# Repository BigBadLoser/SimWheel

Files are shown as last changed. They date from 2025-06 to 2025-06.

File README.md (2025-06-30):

# SimWheel

Source files for my Ferrari SF90 F1 wheel. Uses a PGA2350 as the main processor, 
also uses an Adafruit USB hub of some sort, allows one cable for output even with the VoCore usb screen installed :)

###TODO:
- Fix HAT switch wiring.
- Move upper led_din to a GPIO pin that supports PIO (oops)
- add connectors for the rear 2 push buttons that i forgot

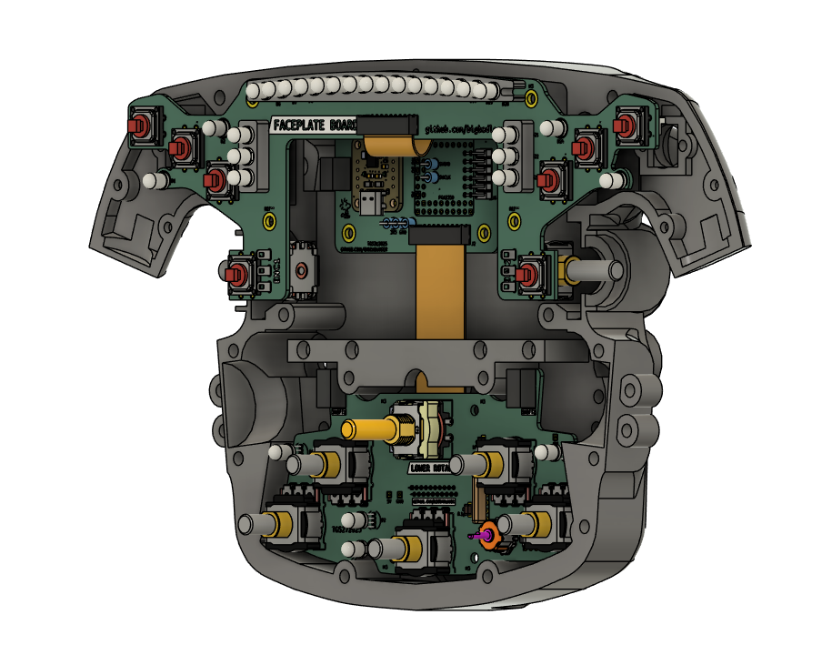
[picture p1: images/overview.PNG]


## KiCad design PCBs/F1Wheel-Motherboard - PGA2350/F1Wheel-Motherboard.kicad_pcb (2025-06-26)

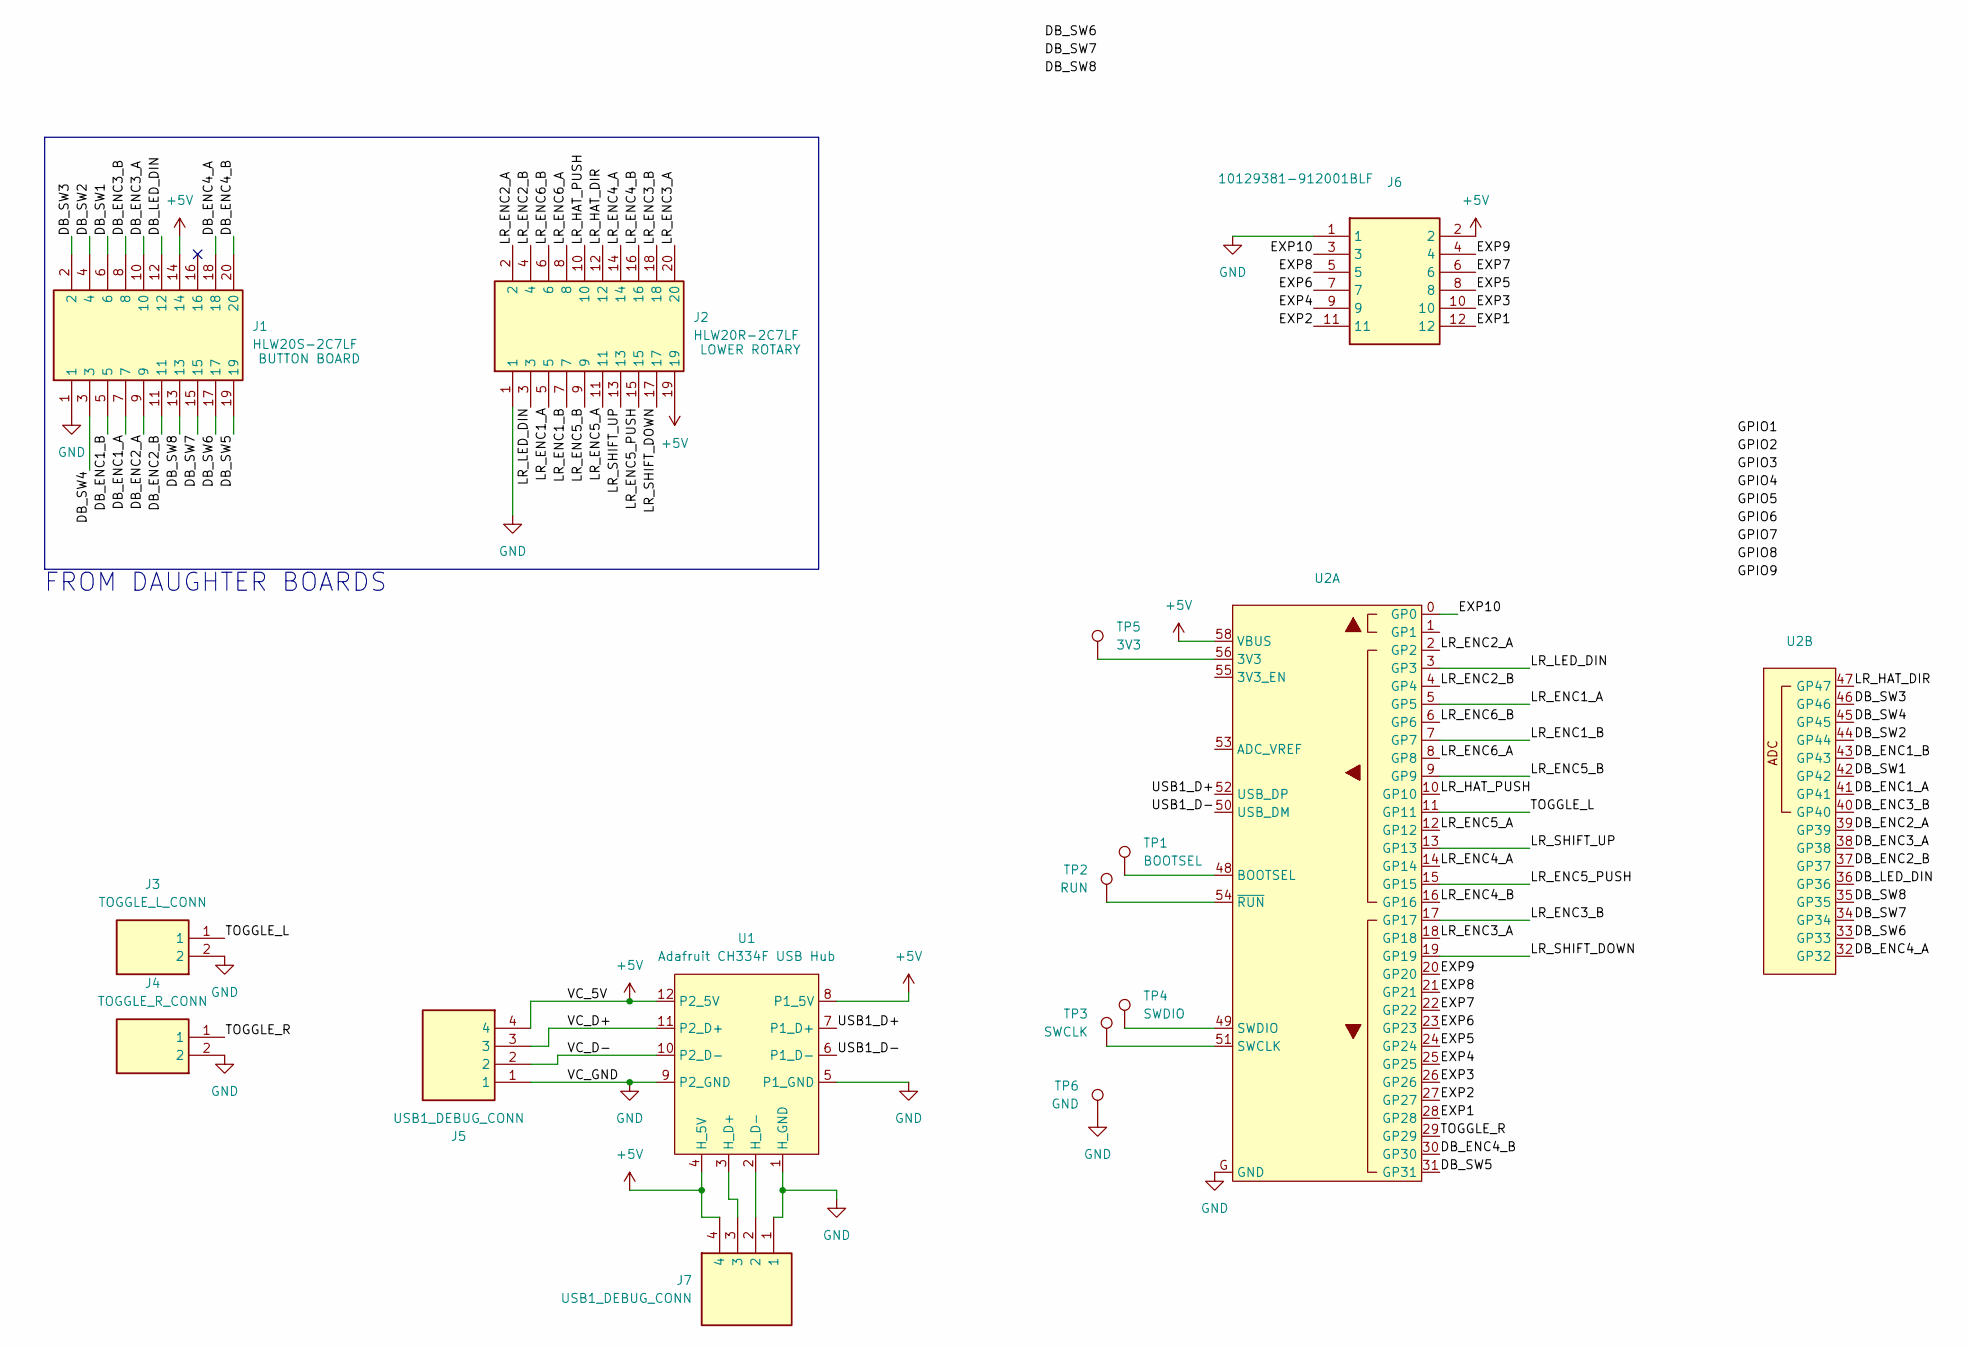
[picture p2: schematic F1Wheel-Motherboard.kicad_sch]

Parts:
J1: HLW20S-2C7LF; AMPHENOL_HLW20S2C7LF; Mouser Part Number 649-HLW16R-2C7LF
J2: HLW20R-2C7LF; AMPHENOL_HLW20R-2C7LF; Mouser Part Number 649-HLW16R-2C7LF
J3: TOGGLE_L_CONN; B02BPASKLFSN; Mouser Part Number 306-B02BPASKLFSN
J4: TOGGLE_R_CONN; B02BPASKLFSN; Mouser Part Number 306-B02BPASKLFSN
J5, J7: USB1_DEBUG_CONN; B04BPASKLFSN; Mouser Part Number 306-B04BPASKLFSN
J6: 10129381-912001BLF; HDRV12W67P254_2X6_1524X483X858P; Manufacturer_Part_Number 10129381-912001BLF
TP1: BOOTSEL; TestPoint_Keystone_5005-5009_Compact
TP2: RUN; TestPoint_Keystone_5005-5009_Compact
TP3: SWCLK; TestPoint_Keystone_5005-5009_Compact
TP4: SWDIO; TestPoint_Keystone_5005-5009_Compact
TP5: 3V3; TestPoint_Keystone_5005-5009_Compact
TP6: GND; TestPoint_Keystone_5005-5009_Compact
U1: Adafruit CH334F USB Hub; Adafruit_CH334F_2Port
U2: PGA2350_ALT

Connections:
+5V: J1.14, J2.19, J5.4, J6.2, J7.4, U1.4 (H_5V), U1.8 (P1_5V), U1.12 (P2_5V), U2.58 (VBUS)
/DB_ENC1_A: J1.7, U2.41 (GP41)
/DB_ENC1_B: J1.5, U2.43 (GP43)
/DB_ENC2_A: J1.9, U2.39 (GP39)
/DB_ENC2_B: J1.11, U2.37 (GP37)
/DB_ENC3_A: J1.10, U2.38 (GP38)
/DB_ENC3_B: J1.8, U2.40 (GP40)
/DB_ENC4_A: J1.18, U2.32 (GP32)
/DB_ENC4_B: J1.20, U2.30 (GP30)
/DB_LED_DIN: J1.12, U2.36 (GP36)
/DB_SW1: J1.6, U2.42 (GP42)
/DB_SW2: J1.4, U2.44 (GP44)
/DB_SW3: J1.2, U2.46 (GP46)
/DB_SW4: J1.3, U2.45 (GP45)
/DB_SW5: J1.19, U2.31 (GP31)
/DB_SW6: J1.17, U2.33 (GP33)
/DB_SW7: J1.15, U2.34 (GP34)
/DB_SW8: J1.13, U2.35 (GP35)
/EXP1: J6.12, U2.28 (GP28)
/EXP2: J6.11, U2.27 (GP27)
/EXP3: J6.10, U2.26 (GP26)
/EXP4: J6.9, U2.25 (GP25)
/EXP5: J6.8, U2.24 (GP24)
/EXP6: J6.7, U2.23 (GP23)
/EXP7: J6.6, U2.22 (GP22)
/EXP8: J6.5, U2.21 (GP21)
/EXP9: J6.4, U2.20 (GP20)
/EXP10: J6.3, U2.0 (GP0)
/LR_ENC1_A: J2.5, U2.5 (GP5)
/LR_ENC1_B: J2.7, U2.7 (GP7)
/LR_ENC2_A: J2.2, U2.2 (GP2)
/LR_ENC2_B: J2.4, U2.4 (GP4)
/LR_ENC3_A: J2.20, U2.18 (GP18)
/LR_ENC3_B: J2.18, U2.17 (GP17)
/LR_ENC4_A: J2.14, U2.14 (GP14)
/LR_ENC4_B: J2.16, U2.16 (GP16)
/LR_ENC5_A: J2.11, U2.12 (GP12)
/LR_ENC5_B: J2.9, U2.9 (GP9)
/LR_ENC5_PUSH: J2.15, U2.15 (GP15)
/LR_ENC6_A: J2.8, U2.8 (GP8)
/LR_ENC6_B: J2.6, U2.6 (GP6)
/LR_HAT_DIR: J2.12, U2.47 (GP47)
/LR_HAT_PUSH: J2.10, U2.10 (GP10)
/LR_LED_DIN: J2.3, U2.3 (GP3)
/LR_SHIFT_DOWN: J2.17, U2.19 (GP19)
/LR_SHIFT_UP: J2.13, U2.13 (GP13)
/TOGGLE_L: J3.1, U2.11 (GP11)
/TOGGLE_R: J4.1, U2.29 (GP29)
/USB1_D+: U1.7 (P1_D+), U2.52 (USB_DP)
/USB1_D-: U1.6 (P1_D-), U2.50 (USB_DM)
/VC_D+: J5.3, U1.11 (P2_D+)
/VC_D-: J5.2, U1.10 (P2_D-)
GND: J1.1, J2.1, J3.2, J4.2, J5.1, J6.1, J7.1, TP6.1, U1.1 (H_GND), U1.5 (P1_GND), U1.9 (P2_GND), U2.G (GND)
unnamed: J7.3, U1.3 (H_D+)
unnamed: J7.2, U1.2 (H_D-)
unnamed: TP5.1, U2.56 (3V3)
unnamed: TP1.1, U2.48 (BOOTSEL)
unnamed: TP3.1, U2.51 (SWCLK)
unnamed: TP4.1, U2.49 (SWDIO)
unnamed: TP2.1, U2.54 (~RUN)

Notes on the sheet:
FROM DAUGHTER BOARDS

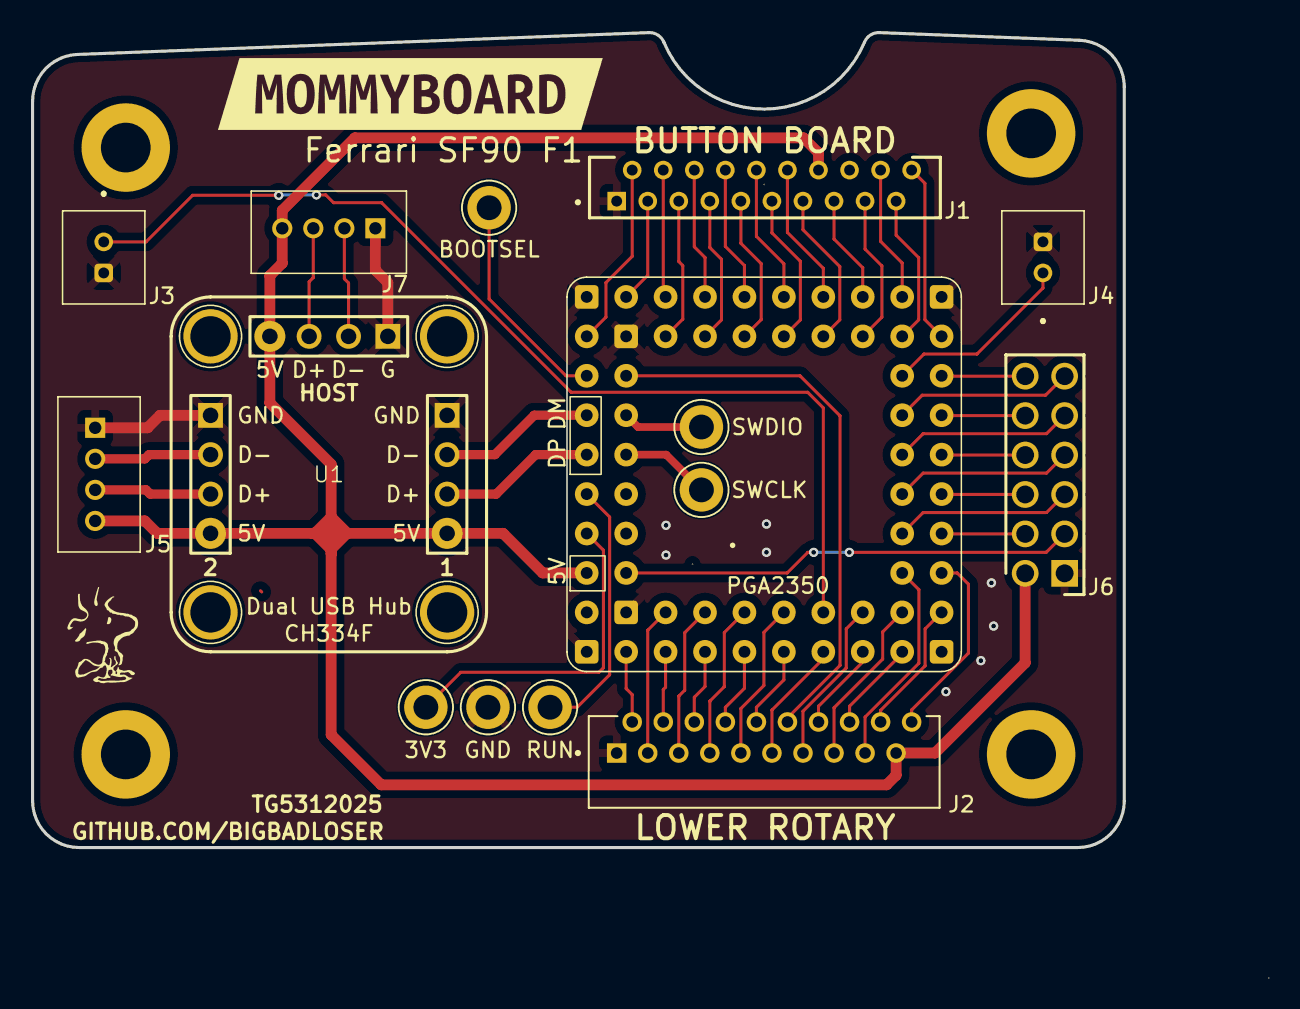
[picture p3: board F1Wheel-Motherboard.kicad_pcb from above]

Board: 2 copper layers, 70.3 x 52.5 mm, 16 parts (0 on the bottom side), 60 nets.

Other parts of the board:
kibuzzard-683A7EFC: G***; kibuzzard-683A7EFC

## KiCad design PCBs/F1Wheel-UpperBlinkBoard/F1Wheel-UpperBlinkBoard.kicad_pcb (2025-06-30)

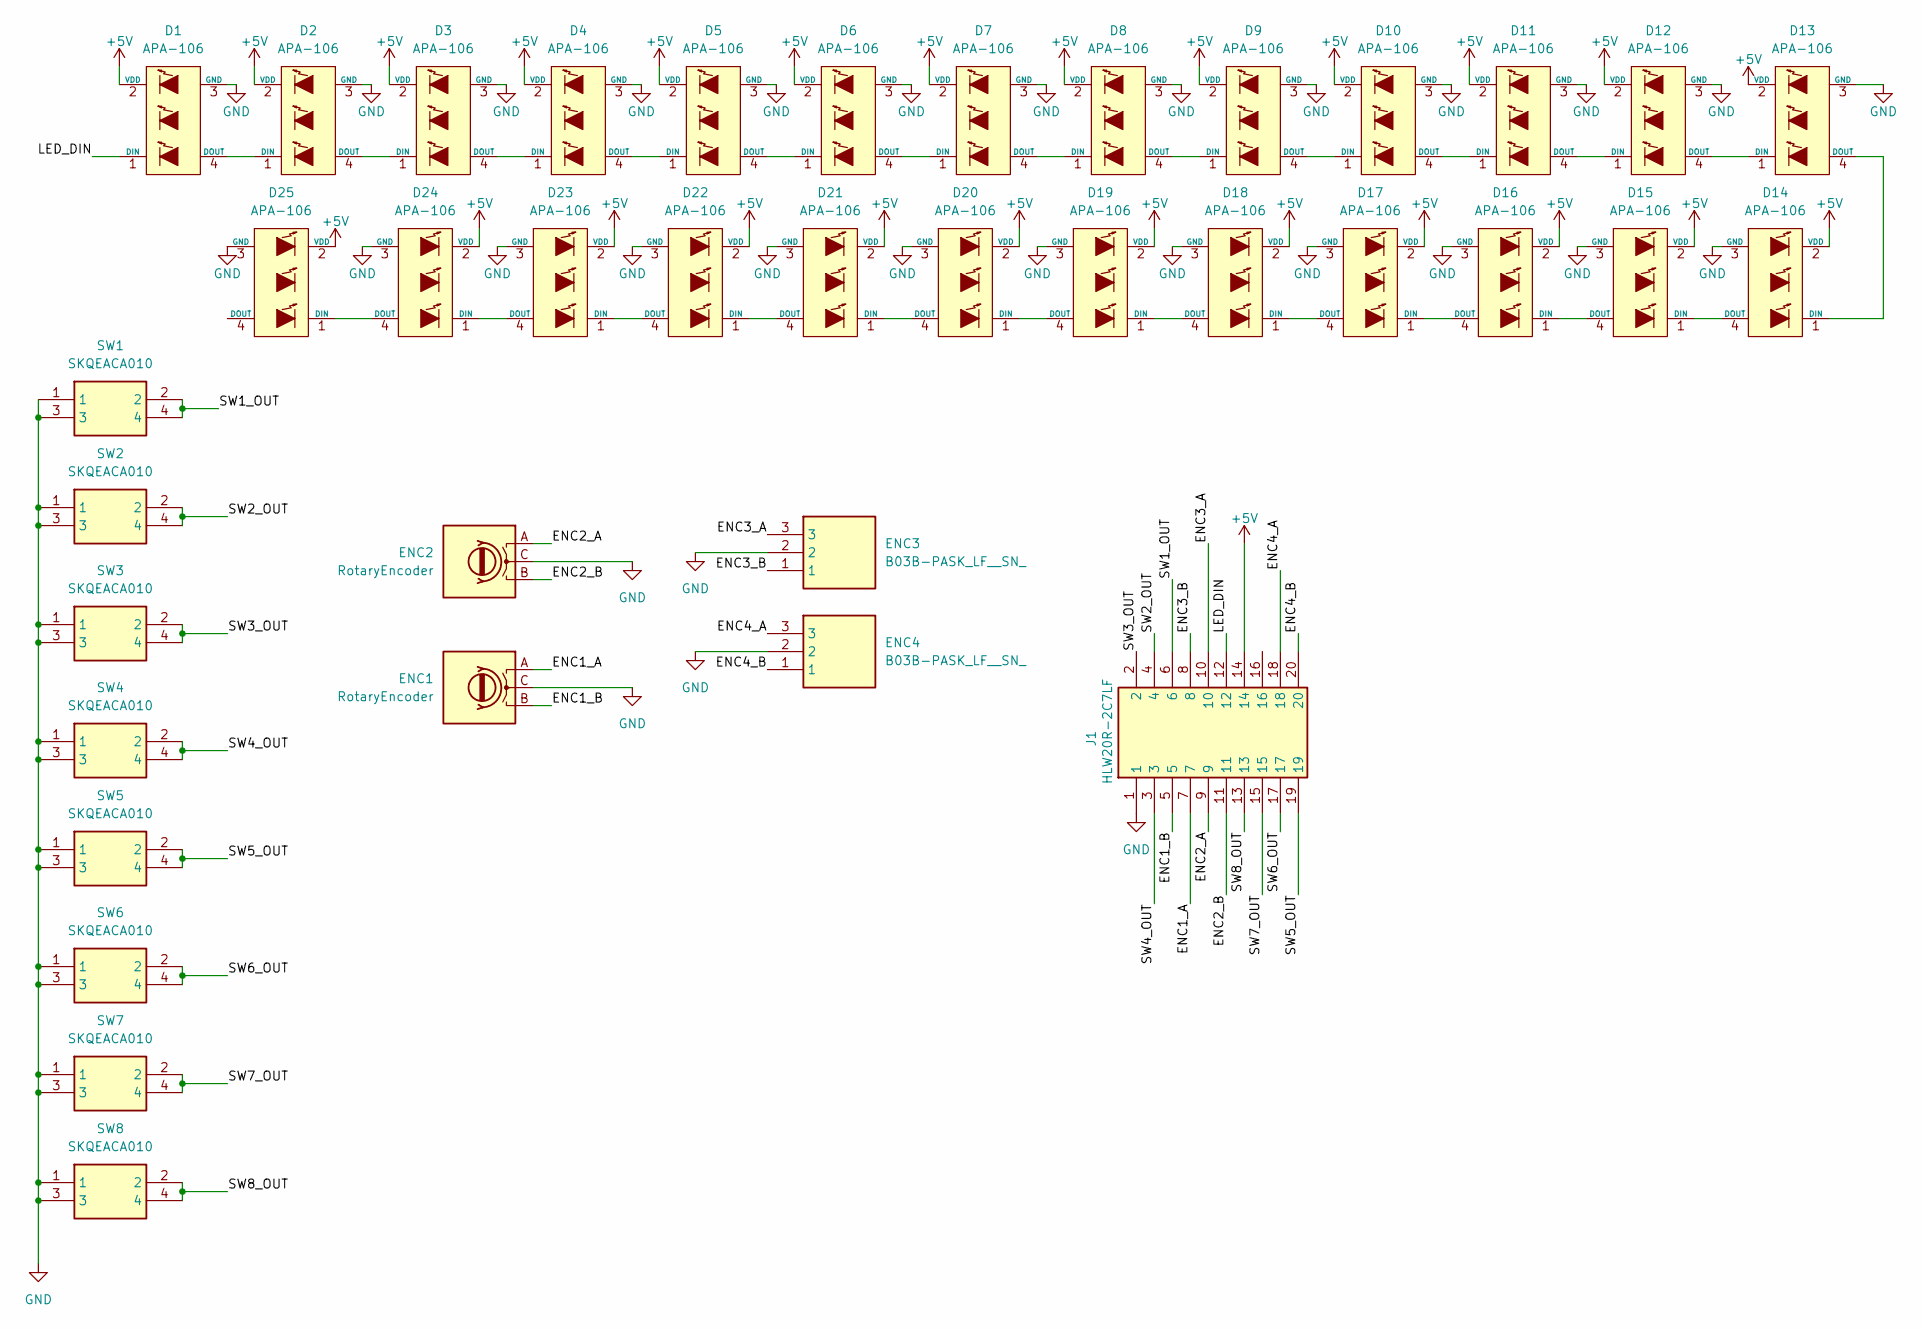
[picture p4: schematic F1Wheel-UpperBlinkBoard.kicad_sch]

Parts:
D1, D2, D3, D4, D5, D6, D7, D8, D9, D10, D11, D12, D13, D14, D15, D16, D17, D18, D19, D20, D21, D22, D23, D24, D25: APA-106; APA-106-F5
ENC1, ENC2: RotaryEncoder; 288T Encoder
ENC3, ENC4: B03B-PASK_LF__SN_; B03BPASKLFSN; Mouser Part Number 306-B03BPASKLFSN
J1: HLW20R-2C7LF; AMPHENOL_HLW20R-2C7LF; Mouser Part Number 649-HLW16R-2C7LF
SW1, SW2, SW3, SW4, SW5, SW6, SW7, SW8: SKQEACA010; Mouser Part Number 688-SKQEAC

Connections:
+5V: D1.2 (VDD), D2.2 (VDD), D3.2 (VDD), D4.2 (VDD), D5.2 (VDD), D6.2 (VDD), D7.2 (VDD), D8.2 (VDD), D9.2 (VDD), D10.2 (VDD), D11.2 (VDD), D12.2 (VDD), D13.2 (VDD), D14.2 (VDD), D15.2 (VDD), D16.2 (VDD), D17.2 (VDD), D18.2 (VDD), D19.2 (VDD), D20.2 (VDD), D21.2 (VDD), D22.2 (VDD), D23.2 (VDD), D24.2 (VDD), D25.2 (VDD), J1.14
/ENC1_A: ENC1.A, J1.7
/ENC1_B: ENC1.B, J1.5
/ENC2_A: ENC2.A, J1.9
/ENC2_B: ENC2.B, J1.11
/ENC3_A: ENC3.3, J1.10
/ENC3_B: ENC3.1, J1.8
/ENC4_A: ENC4.3, J1.18
/ENC4_B: ENC4.1, J1.20
/LED_DIN: D1.1 (DIN), J1.12
/SW1_OUT: J1.6, SW1.2, SW1.4
/SW2_OUT: J1.4, SW2.2, SW2.4
/SW3_OUT: J1.2, SW3.2, SW3.4
/SW4_OUT: J1.3, SW4.2, SW4.4
/SW5_OUT: J1.19, SW5.2, SW5.4
/SW6_OUT: J1.17, SW6.2, SW6.4
/SW7_OUT: J1.15, SW7.2, SW7.4
/SW8_OUT: J1.13, SW8.2, SW8.4
GND: D1.3 (GND), D2.3 (GND), D3.3 (GND), D4.3 (GND), D5.3 (GND), D6.3 (GND), D7.3 (GND), D8.3 (GND), D9.3 (GND), D10.3 (GND), D11.3 (GND), D12.3 (GND), D13.3 (GND), D14.3 (GND), D15.3 (GND), D16.3 (GND), D17.3 (GND), D18.3 (GND), D19.3 (GND), D20.3 (GND), D21.3 (GND), D22.3 (GND), D23.3 (GND), D24.3 (GND), D25.3 (GND), ENC1.C, ENC2.C, ENC3.2, ENC4.2, J1.1, SW1.1, SW1.3, SW2.1, SW2.3, SW3.1, SW3.3, SW4.1, SW4.3, SW5.1, SW5.3, SW6.1, SW6.3, SW7.1, SW7.3, SW8.1, SW8.3
unnamed: D1.4 (DOUT), D2.1 (DIN)
unnamed: D2.4 (DOUT), D3.1 (DIN)
unnamed: D3.4 (DOUT), D4.1 (DIN)
unnamed: D4.4 (DOUT), D5.1 (DIN)
unnamed: D5.4 (DOUT), D6.1 (DIN)
unnamed: D6.4 (DOUT), D7.1 (DIN)
unnamed: D7.4 (DOUT), D8.1 (DIN)
unnamed: D8.4 (DOUT), D9.1 (DIN)
unnamed: D9.4 (DOUT), D10.1 (DIN)
unnamed: D10.4 (DOUT), D11.1 (DIN)
unnamed: D11.4 (DOUT), D12.1 (DIN)
unnamed: D12.4 (DOUT), D13.1 (DIN)
unnamed: D13.4 (DOUT), D14.1 (DIN)
unnamed: D14.4 (DOUT), D15.1 (DIN)
unnamed: D15.4 (DOUT), D16.1 (DIN)
unnamed: D16.4 (DOUT), D17.1 (DIN)
unnamed: D17.4 (DOUT), D18.1 (DIN)
unnamed: D18.4 (DOUT), D19.1 (DIN)
unnamed: D19.4 (DOUT), D20.1 (DIN)
unnamed: D20.4 (DOUT), D21.1 (DIN)
unnamed: D21.4 (DOUT), D22.1 (DIN)
unnamed: D22.4 (DOUT), D23.1 (DIN)
unnamed: D23.4 (DOUT), D24.1 (DIN)
unnamed: D24.4 (DOUT), D25.1 (DIN)

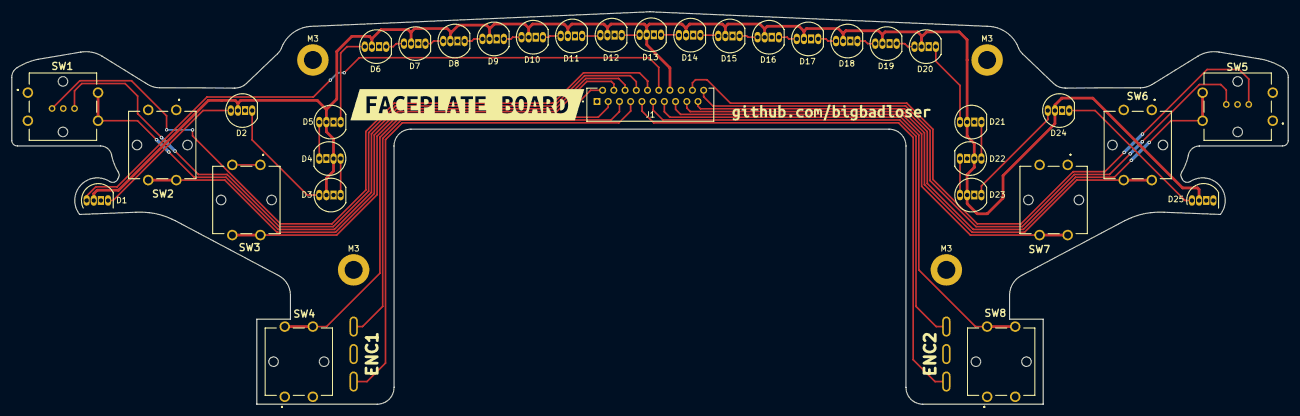
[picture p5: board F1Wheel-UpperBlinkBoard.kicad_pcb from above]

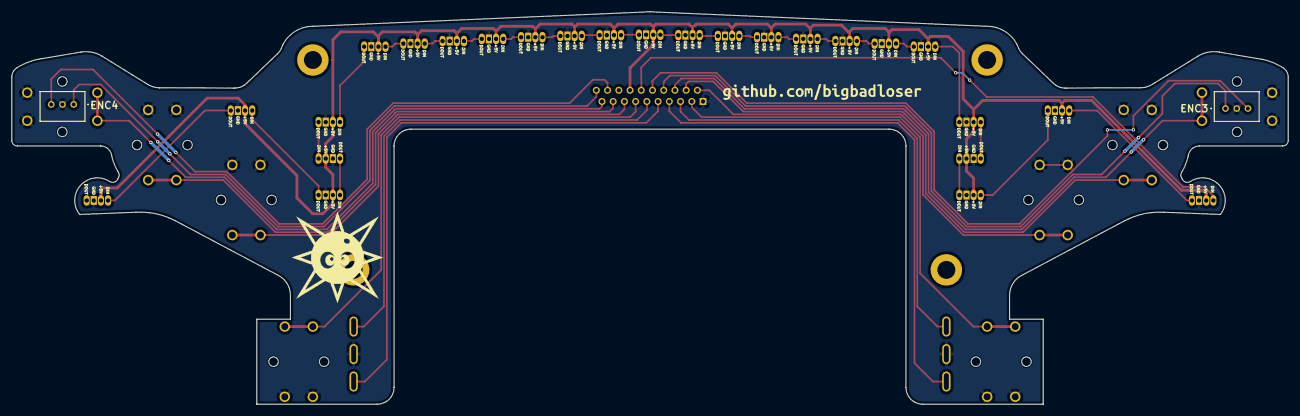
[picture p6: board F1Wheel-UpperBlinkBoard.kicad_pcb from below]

Board: 2 copper layers, 227.4 x 69.9 mm, 45 parts (3 on the bottom side), 43 nets.

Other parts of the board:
M3, M3#2, M3#3, M3#4: MountingHole_3.2mm_M3_DIN965_Pad
kibuzzard-683245A1, kibuzzard-683245A1#2: G***; kibuzzard-683245A1
kibuzzard-683248CA: G***; kibuzzard-683248CA

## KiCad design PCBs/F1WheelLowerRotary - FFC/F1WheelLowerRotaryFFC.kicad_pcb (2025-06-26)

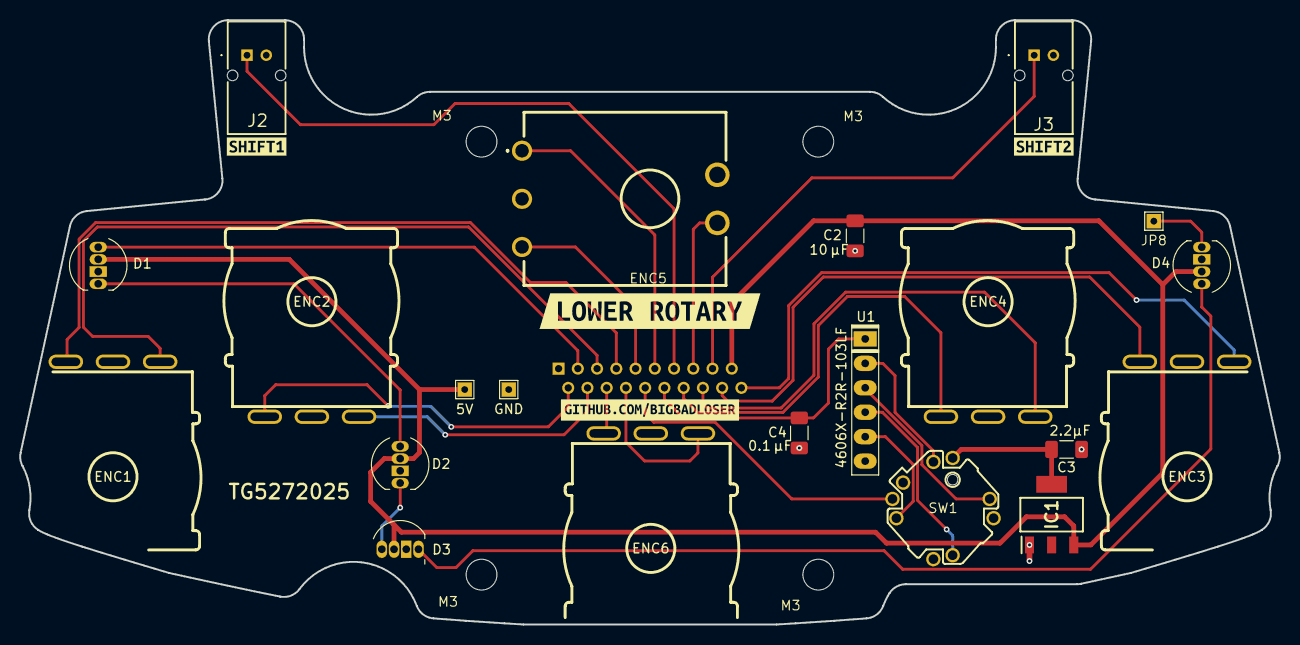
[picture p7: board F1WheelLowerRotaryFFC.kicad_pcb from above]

Board: 2 copper layers, 130.9 x 62.8 mm, 30 parts (1 on the bottom side), 29 nets.

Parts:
5V: 5V; TestPoint_THTPad_1.5x1.5mm_Drill0.7mm
C2: 10 µF; C_1206_3216Metric_Pad1.33x1.80mm_HandSolder
C3: 2.2µF; C_1206_3216Metric_Pad1.33x1.80mm_HandSolder
C4: 0.1 µF; C_1206_3216Metric_Pad1.33x1.80mm_HandSolder
D1, D2, D3, D4: APA-106; LED_D5.0mm-APA106
ENC1, ENC2, ENC3, ENC4, ENC6: RotaryEncoder; 288T Encoder
ENC5: 288V232R161B2
GND: GND; TestPoint_THTPad_1.5x1.5mm_Drill0.7mm
IC1: TLV76133DCYR; SOT230P700X180-4N
J2: SW_SHIFT1; JST_S02B-PASK-2
J3: SW_SHIFT2; JST_S02B-PASK-2
J14: HLW20R-2C7LF; AMPHENOL_HLW20R-2C7LF
JP8: DOUT; TestPoint_THTPad_1.5x1.5mm_Drill0.7mm
M3, M3#2, M3#3, M3#4: MountingHole_3.2mm_M3
SW1: RKJXM1015004
U1: 4606X-R2R-103LF; R_Array_SIP6_BigPads
kibuzzard-682F5760: G***; kibuzzard-682F5760
kibuzzard-682F5782: G***; kibuzzard-682F5782
kibuzzard-68364A1D: G***; kibuzzard-68364A1D
kibuzzard-683649BF: G***; kibuzzard-683649BF

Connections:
+3.3V: C3.2, IC1.2 (OUT_1), IC1.4 (OUT_2), SW1.COM
+5V: 5V.1, C2.2, D1.2 (VDD), D2.2 (VDD), D3.2 (VDD), D4.2 (VDD), IC1.3 (IN), J14.19
/HAT_DOWN: SW1.C (DOWN), U1.2 (BIT1)
/HAT_LEFT: SW1.B (LEFT), U1.3 (BIT2)
/HAT_RIGHT: SW1.D (RIGHT), U1.5 (BIT4)
/HAT_UP: SW1.A (UP), U1.4 (BIT3)
/LR_ENC1_A: ENC1.A, J14.5
/LR_ENC1_B: ENC1.B, J14.7
/LR_ENC2_A: ENC2.A, J14.2
/LR_ENC2_B: ENC2.B, J14.4
/LR_ENC3_A: ENC3.A, J14.20
/LR_ENC3_B: ENC3.B, J14.18
/LR_ENC4_A: ENC4.A, J14.14
/LR_ENC4_B: ENC4.B, J14.16
/LR_ENC5_A: ENC5.A1, J14.11
/LR_ENC5_B: ENC5.B1, J14.9
/LR_ENC5_PUSH: ENC5.S2, J14.15
/LR_ENC6_A: ENC6.A, J14.8
/LR_ENC6_B: ENC6.B, J14.6
/LR_HAT_DIR: C4.2, J14.12, U1.1 (OUT)
/LR_HAT_PUSH: J14.10, SW1.PUSH
/LR_LED_DIN: D1.1 (DIN), J14.3
/LR_SHIFT_DOWN: J3.1, J14.17
/LR_SHIFT_UP: J2.1, J14.13
GND: C2.1, C3.1, C4.1, D1.3 (GND), D2.3 (GND), D3.3 (GND), D4.3 (GND), ENC1.C, ENC2.C, ENC3.C, ENC4.C, ENC5.C1, ENC5.S1, ENC6.C, GND.1, IC1.1 (GND), J2.2, J3.2, J14.1, U1.6 (RT)
unnamed: D1.4 (DOUT), D2.1 (DIN)
unnamed: D2.4 (DOUT), D3.1 (DIN)
unnamed: D3.4 (DOUT), D4.1 (DIN)
unnamed: D4.4 (DOUT), JP8.1

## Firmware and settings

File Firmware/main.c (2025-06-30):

#include <stdio.h>
#include <string.h>
#include <stdlib.h>
#include "pico/stdlib.h"
#include "hardware/clocks.h"
#include "hardware/pio.h"
#include "tusb.h"
#include "ws2812.pio.h"
#include "bsp/board.h"
#include "gpio.h"
#include "commands.h"
#include "leds.h"

#define LED_PIN         3 
#define NUM_LEDS        4
#define UPPER_NUM_LEDS 25
#define UPPER_LED_PIN 27
#define BRIGHTNESS      0.5f

volatile bool led_dirty = false;

static PIO pio = pio0;
static uint sm = 0;
static uint sm1 = 1;
static uint offset;

static InputReport last_input_report = {
    .hat = "invalid"
};



// ---------- Main ----------

void inputPollReport(){
    tud_task();
    update_input_report();
    char json_buffer[512];
    build_input_report_json(&input_report, json_buffer, sizeof(json_buffer));

    if (tud_cdc_connected() && tud_cdc_write_available() >= strlen(json_buffer) + 2) {
        if (input_report_changed(&input_report, &last_input_report)) {
            build_input_report_json(&input_report, json_buffer, sizeof(json_buffer));
            tud_cdc_n_write_str(0, json_buffer);
            tud_cdc_n_write_str(0, "\n");
            tud_cdc_n_write_flush(0);
            last_input_report = input_report; // Shallow copy is fine since it has no dynamic allocations
}
        }
}

void update_LEDs(){
    leds_tick_animation(); // Update any animations
    if(c_get_led_dirty()) {
        c_show_upper_leds(pio, sm1);
        c_show_lower_leds(pio, sm);
        c_clear_led_dirty();
    }
}

void send_color(uint32_t color){
    for (int i = 0; i < UPPER_NUM_LEDS; i++) {
        pio_sm_put_blocking(pio, sm1, color);
    }
}
#define POLL_INTERVAL_MS 25
#define DELAY_MS 50
int main() {
    board_init();
    tusb_init();
    sleep_ms(500); // Allow time for USB to initialize
    gpio_inputs_init(); // initializes all GPIOs
    stdio_init_all();
    offset = pio_add_program(pio, &ws2812_program);
    register_all_commands();
    ws2812_program_init(pio, sm, offset, LED_PIN, 700000, false);
    ws2812_program_init(pio, sm1, offset, UPPER_LED_PIN, 700000, false);

    while (!tud_cdc_connected()) {
        tud_task();
        sleep_ms(10);
    }

    absolute_time_t next_poll = make_timeout_time_ms(POLL_INTERVAL_MS);
    while (true) {
        tud_task();
        char serial_buf[128];
        static int serial_index = 0;
        while (tud_cdc_available()) {
            char c = tud_cdc_read_char();
            if (c == '\n' || c == '\r') {
                serial_buf[serial_index] = '\0';
                tud_cdc_write_str("Received: ");
                tud_cdc_write_str(serial_buf);
                tud_cdc_write_str("\r\n");
                tud_cdc_write_flush();
                dispatch_json_command(serial_buf);
                serial_index = 0;
            } else if (serial_index < sizeof(serial_buf) - 1) {
                serial_buf[serial_index++] = c;
            }
        }
        if (absolute_time_diff_us(get_absolute_time(), next_poll) <= 0) {
            next_poll = make_timeout_time_ms(POLL_INTERVAL_MS);
            inputPollReport(); // refresh input_report from GPIOs
            update_LEDs();
        }
            
    }
}

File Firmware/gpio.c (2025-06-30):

#include <stdint.h>
#include <string.h>
#include <stdio.h>
#include <stdbool.h>
#include "hardware/gpio.h"
#include "hardware/adc.h"
#include "gpio.h"
#include "hardware/regs/io_bank0.h"
#include "hardware/structs/ioqspi.h"
#include "hardware/structs/sio.h"

//LR ENCODER A PINS: 5, 2, 18, 14, 12, 8
//LR ENCODER B PINS: 7, 4, 17, 16, 9, 6
//DB ENCODER A PINS: 41, 39, 38, 32
//DB ENCODER B PINS: 43, 37, 40, 30

const uint8_t encoder_A_pins[ENCODER_COUNT] = {5, 2, 18, 14, 12, 8, 41, 39, 38, 32};
const uint8_t encoder_B_pins[ENCODER_COUNT] = {7, 4, 17, 16, 9, 6, 43, 37, 40, 30};
int8_t encoder_deltas[ENCODER_COUNT] = { 0 };
uint8_t encoder_last_state[ENCODER_COUNT] = { 0 };

const uint8_t button_pins[BUTTON_COUNT] = { 46, 45, 42, 44, 33, 34, 35, 31}; //46, 45, 42, 44, 33, 34, 35, 31
const uint8_t toggle_pins[TOGGLE_COUNT] = { 11, 29};
const uint8_t shift_pins[SHIFT_COUNT] = { 19, 13};




// === Internal Struct ===
InputReport input_report;
static int last_encoder_state[ENCODER_COUNT];

// === Utility: Hat Switch Decode ===
const char* decode_hat_adc(uint16_t raw) {
    /*
    if (raw > 2980) return "down";
    else if (raw > 2950) return "left";
    else if (raw > 2870) return "up";
    else if (raw > 2815) return "right";
    else if (raw > 2700)  return "none";
    else return "unknown";
    */
   return "unknown";
}

bool input_report_changed(const InputReport* a, const InputReport* b) {
    if (memcmp(a->buttons, b->buttons, sizeof(a->buttons)) != 0) return true;
    if (memcmp(a->toggles, b->toggles, sizeof(a->toggles)) != 0) return true;
    if (memcmp(a->shifters, b->shifters, sizeof(a->shifters)) != 0) return true;
    if (memcmp(a->encoders, b->encoders, sizeof(a->encoders)) != 0) return true;
    if ((a->hat_button && !b->hat_button) || (!a->hat_button && b->hat_button)) return true;
    if ((a->hat && !b->hat) || (!a->hat && b->hat)) return true;
    if (a->hat && b->hat && strcmp(a->hat, b->hat) != 0) return true;
    
    return false;
}
/*
bool input_report_changed(const InputReport* a, const InputReport* b) {
    if (a->hat != b->hat && (!a->hat || !b->hat || strcmp(a->hat, b->hat) != 0))
        return true;

    for (int i = 0; i < BUTTON_COUNT; ++i)
        if (a->buttons[i] != b->buttons[i]) return true;

    for (int i = 0; i < TOGGLE_COUNT; ++i)
        if (a->toggles[i] != b->toggles[i]) return true;

    for (int i = 0; i < SHIFT_COUNT; ++i)
        if (a->shifters[i] != b->shifters[i]) return true;

    for (int i = 0; i < ENCODER_COUNT; ++i)
        if (a->encoders[i] != b->encoders[i]) return true;

    return false;
}
*/

// === Quadrature Decoder ===
void update_encoder_values(int encoders[ENCODER_COUNT]) {
    for (int i = 0; i < ENCODER_COUNT; i++) {
        int a = gpio_get(encoder_A_pins[i]);
        int b = gpio_get(encoder_B_pins[i]);
        int current = (a << 1) | b;
        int last = last_encoder_state[i];
        int delta = 0;

        if ((last == 0b00 && current == 0b01) ||
            (last == 0b01 && current == 0b11) ||
            (last == 0b11 && current == 0b10) ||
            (last == 0b10 && current == 0b00)) {
            delta = 1;
        } else if ((last == 0b00 && current == 0b10) ||
                   (last == 0b10 && current == 0b11) ||
                   (last == 0b11 && current == 0b01) ||
                   (last == 0b01 && current == 0b00)) {
            delta = -1;
        }

        encoders[i] += delta;
        last_encoder_state[i] = current;
    }
}

// === Setup GPIOs ===
void gpio_inputs_init(void) {
    //Enable all momentary push buttons
    for (int i = 0; i < BUTTON_COUNT; i++) gpio_init(button_pins[i]), gpio_set_dir(button_pins[i], false), gpio_pull_up(button_pins[i]);
    //Enable all toggle switches
    for (int i = 0; i < TOGGLE_COUNT; i++) gpio_init(toggle_pins[i]), gpio_set_dir(toggle_pins[i], false);
    //Enable the 2 shift buttons
    for (int i = 0; i < SHIFT_COUNT; i++) gpio_init(shift_pins[i]), gpio_set_dir(shift_pins[i], false), gpio_pull_up(shift_pins[i]);
    //Enable the encoders
    for (int i = 0; i < ENCODER_COUNT; i++) {
        gpio_init(encoder_A_pins[i]); gpio_set_dir(encoder_A_pins[i], false); gpio_pull_up(encoder_A_pins[i]);
        gpio_init(encoder_B_pins[i]); gpio_set_dir(encoder_B_pins[i], false); gpio_pull_up(encoder_B_pins[i]);
        last_encoder_state[i] = (gpio_get(encoder_A_pins[i]) << 1) | gpio_get(encoder_B_pins[i]);
    }
    //Enable the hat switch push button and ADC
    gpio_init(HAT_BUTTON_PIN); gpio_set_dir(HAT_BUTTON_PIN, false); gpio_pull_down(HAT_BUTTON_PIN);
    adc_init();
    gpio_set_function(HAT_DIR_PIN, 0);
    gpio_disable_pulls(HAT_DIR_PIN);  // disables both pull-up/down
}
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

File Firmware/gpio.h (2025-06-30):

#ifndef GPIO_H
#define GPIO_H

#include <stdbool.h>
#include <stdint.h>

// Pin counts
#define ENCODER_COUNT 10
#define BUTTON_COUNT 8
#define TOGGLE_COUNT 2
#define SHIFT_COUNT 2
#define BUTTON_COUNT 8
#define TOGGLE_COUNT 2
#define SHIFT_COUNT 2
#define ENCODER_COUNT 10
#define HAT_DIR_PIN 47
#define HAT_BUTTON_PIN 10
#define HAT_ADC_CHANNEL 7  // GPIO 47 = ADC7 = hat switch

// Input report structure
typedef struct {
    bool buttons[BUTTON_COUNT];
    bool toggles[TOGGLE_COUNT];
    bool shifters[SHIFT_COUNT];
    int encoders[ENCODER_COUNT];
    bool hat_button; 
    uint16_t hat_adc; 
    const char* hat;
} InputReport;

// Global state
extern InputReport input_report;
extern const uint8_t encoder_A_pins[ENCODER_COUNT];
extern const uint8_t encoder_B_pins[ENCODER_COUNT];
extern int8_t encoder_deltas[ENCODER_COUNT];
extern uint8_t encoder_last_state[ENCODER_COUNT];

extern const uint8_t button_pins[BUTTON_COUNT];
extern const uint8_t toggle_pins[TOGGLE_COUNT];
extern const uint8_t shift_pins[SHIFT_COUNT];

// Functions
void gpio_inputs_init();
void update_input_report();
InputReport* get_input_report();
const char* decode_hat_adc(uint16_t raw);
void update_encoder_values();
void build_input_report_json(const InputReport* report, char* out, size_t max_len);
bool input_report_changed(const InputReport* a, const InputReport* b);
#endif // GPIO_H
